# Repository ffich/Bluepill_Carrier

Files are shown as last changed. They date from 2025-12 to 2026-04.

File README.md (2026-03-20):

# BluePill Experimental Carrier

🧪 **BluePill Experimental Carrier** is a carrier board designed for development, testing, and rapid experimentation with the **STM32 Blue Pill (STM32F103)**.

The goal of this board is to provide a **feature-rich development platform** with integrated peripherals, industrial communication interfaces, and expansion sockets, while keeping the design clean, educational, and easy to extend.

---

## ✨ Key Features

### On-board Peripherals
- 14 × Status / debug LEDs  
- 3 × User buttons  
- 1 × Wake-up button  
- 1 × Analog potentiometer  
- **TMP102** I2C temperature sensor  
- **I²C OLED** display  
- **SPI EEPROM**  

### Communications
- **CAN bus TJA1051T3** transceiver
- **LIN Bus TJA1029T** transceiver (Configurable Master/Slave)
- **RS-485** interface with dedicated transceiver
- **USB / Serial** interface

### Security
- **Microchip ATECC608C** Cryptographic coprocessor

### Expansion Sockets
- External **DS3231 RTC Breakout** socket  
- **BME280** environmental sensor socket  



---

## 🎯 Design Philosophy

- Built for **experimentation, prototyping, and hardware/software testing**
- Well suited for:
  - Embedded development
  - Industrial and automotive communications (CAN, LIN, RS-485)
  - Sensor integration
  - Industrial and IoT applications
  - Cybersecurity

---

## 🧩 Target Audience

- Advanced makers  
- Electronics / embedded students  
- STM32 firmware developers  
- Educational labs and R&D teams  

---

## ⚠️ Disclaimer

This board is **experimental by design**.  
Layout, features, and routing may evolve as the project progresses and new tests are performed.

---

## 📜 License

Hardware and documentation are released under an open-source license.  
See the `LICENSE` file for details.

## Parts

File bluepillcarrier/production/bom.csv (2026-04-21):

Designator | Footprint | Quantity | Value | LCSC Part #
C1, C2, C3, C4, C5, C6 | 0402 | 6 | 100nF | C155422
CN1 | USB_C_Receptacle_HRO_TYPE-C-31-M-12 | 1 | USB | C165948
CN10 | PinSocket_1x07_P2.54mm_Vertical | 1 | IO | C22438157
CN11 | JST_SH_SM04B-SRSS-TB_1x04-1MP_P1.00mm_Horizontal | 1 | QWIIC | C160404
CN2 | PhoenixContact_MSTBA_2,5_2-G-5,08_1x02_P5.08mm_Horizontal | 1 | Can | C441204
CN4 | PinSocket_1x06_P2.54mm_Vertical | 1 | RTC | C2832269
CN5 | PhoenixContact_MSTBA_2,5_2-G-5,08_1x02_P5.08mm_Horizontal | 1 | RS485 | C441204
CN7 | PinSocket_1x04_P2.54mm_Vertical | 1 | BME | C2718488
CN9 | PinHeader_1x03_P2.54mm_Vertical | 1 | Lin | C49257
D1 | D_SMA | 1 | D_Schottky | C412514
D2 | D_SOD-123 | 1 | 1N4148W | C2099
JP1 | PinHeader_1x02_P2.54mm_Vertical | 1 | CAN Term | C5360898
JP2 | PinHeader_1x02_P2.54mm_Vertical | 1 | RS485 Term | C5360898
JP3 | PinHeader_1x02_P2.54mm_Vertical | 1 | USB pwr | C5360898
JP4 | PinHeader_1x03_P2.54mm_Vertical | 1 | Lin_Vbat | C49257
JP5 | PinHeader_1x02_P2.54mm_Vertical | 1 | Lin master | C5360898
LD1, LD10, LD11, LD12, LD13, LD14, LD15, LD16, LD2, LD3, LD4, LD5, LD6, LD9 | 0603 | 14 | Led Blue | C2288
LD7, LD8 | 0603 | 2 | Led Red | C2286
MODULE1A | YAAJ_BluePill_SWD_1 | 1 | YAAJ_BluePill_Part_Like_SWD_Breakout | C2905423
MODULE1B | YAAJ_BluePill_SWD_1 | 1 | YAAJ_BluePill_Part_Like_SWD_Breakout | C2905423
OLED1 | MODULE_DM-OLED096-636 | 1 | OLED | C5248080
R1, R12, R13, R19, R22, R24, R26, R3, R7 | 0402 | 9 | 10k | C174175
R10, R11, R17, R18, R2, R20, R21, R23, R27, R28, R29, R30, R31, R32, R4, R6, R9 | 0402 | 17 | 1k | C140196
R14, R15 | 0603 | 2 | 2.2k
R16, R25 | 0603 | 2 | 120 | C177328
R5, R8 | 0402 | 2 | 5.1k | C25905
RV1 | Potentiometer_Bourns_3386P_Vertical | 1 | Tr | C116303
SW1, SW2, SW3, SW4 | SW_SPST_PTS810 | 4 | Usr1 | C221895
U1 | JEITA_SOIC-8_3.9x4.9mm_P1.27mm | 1 | CH340N | C2977777
U2 | SOIC-8_3.9x4.9mm_P1.27mm | 1 | M95512-WMN6TP | C7567
U3 | SOIC-8_3.9x4.9mm_P1.27mm | 1 | TJA1051T-3 | C38695
U4 | SOT-563 | 1 | TMP102xxDRL | C99269
U5 | SOIC-8_3.9x4.9mm_P1.27mm | 1 | TJA1029T | C194435
U6 | SOIC-8_3.9x4.9mm_P1.27mm | 1 | MAX3485EESA+T | C9943
U7 | SOIC-8_3.9x4.9mm_P1.27mm | 1 | ATECC608A-SSHDA | C28975195

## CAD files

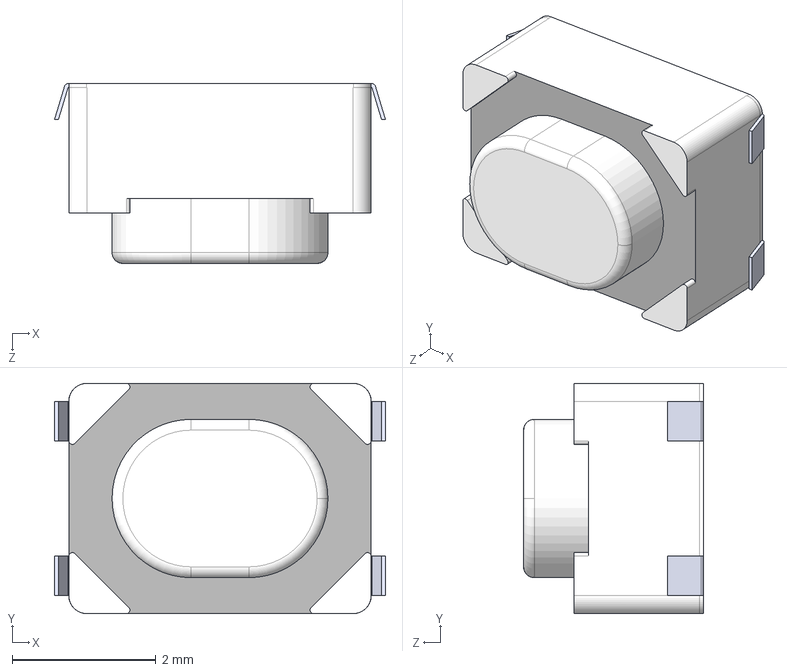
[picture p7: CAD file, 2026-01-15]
bluepillcarrier/3d/PTS810 Series SJS 250.STEP
4.60 x 3.20 x 2.50 mm

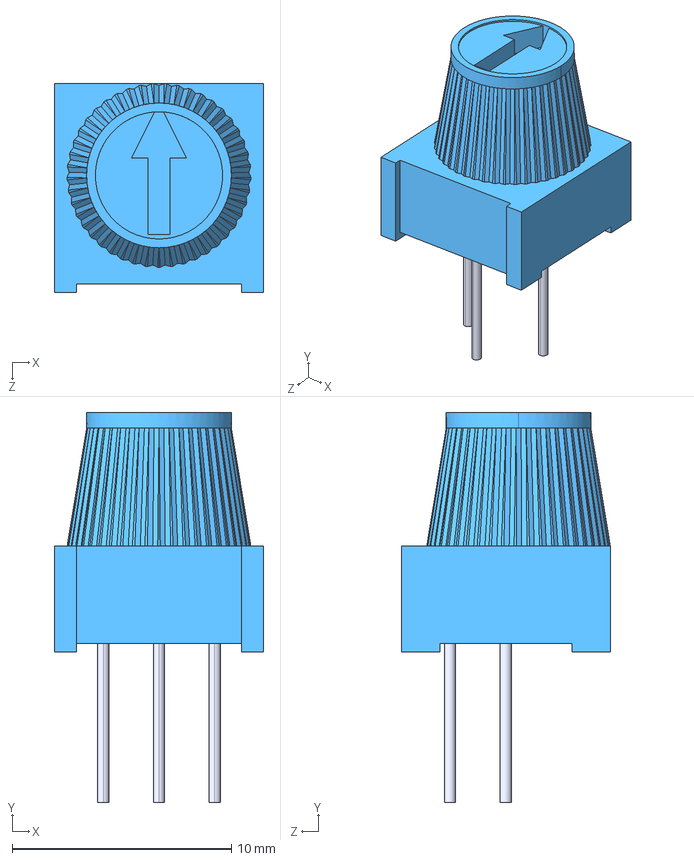
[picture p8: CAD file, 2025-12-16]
bluepillcarrier/3d/3386P-1-104TLF.STEP
9.53 x 17.8 x 9.53 mm

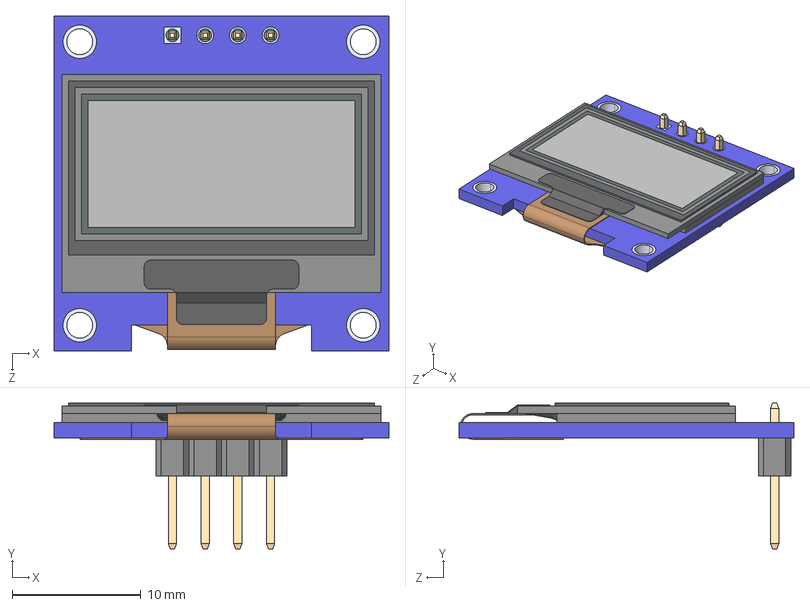
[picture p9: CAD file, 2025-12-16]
bluepillcarrier/3d/DM-OLED096-636--3DModel-STEP-56544.STEP
26.0 x 11.3 x 26.0 mm
DM-OLED096-636_Module
DM-OLED096-636_Panel

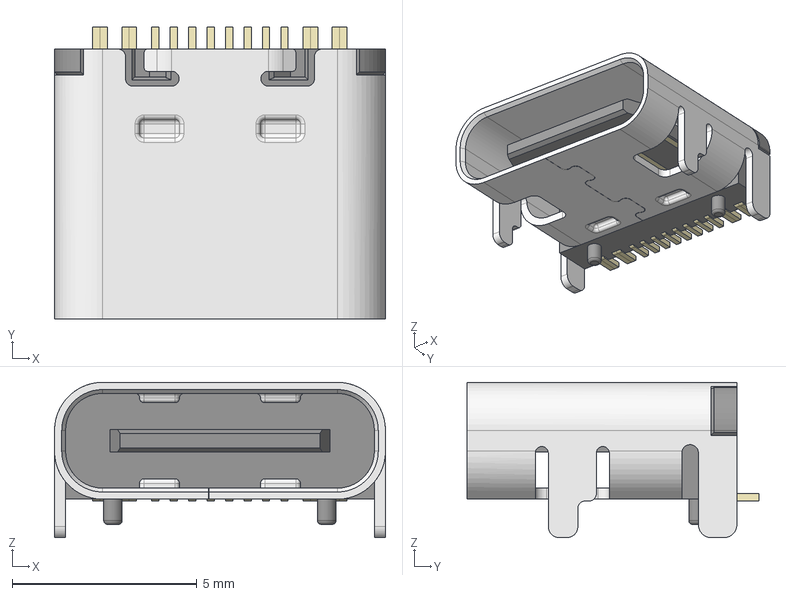
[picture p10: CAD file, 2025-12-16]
bluepillcarrier/3d/HRO_TYPE-C-31-M-12.step
8.95 x 7.90 x 4.20 mm

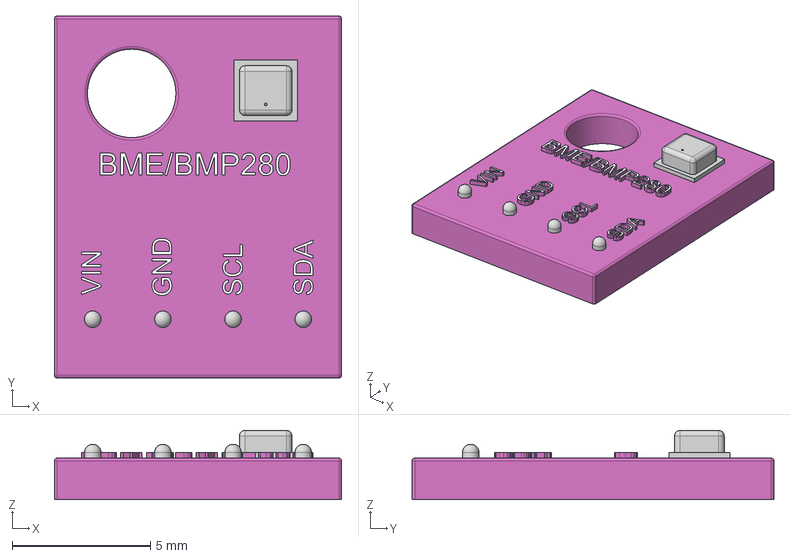
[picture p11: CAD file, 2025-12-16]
bluepillcarrier/3d/BME280 v6.step
10.4 x 13.1 x 2.50 mm

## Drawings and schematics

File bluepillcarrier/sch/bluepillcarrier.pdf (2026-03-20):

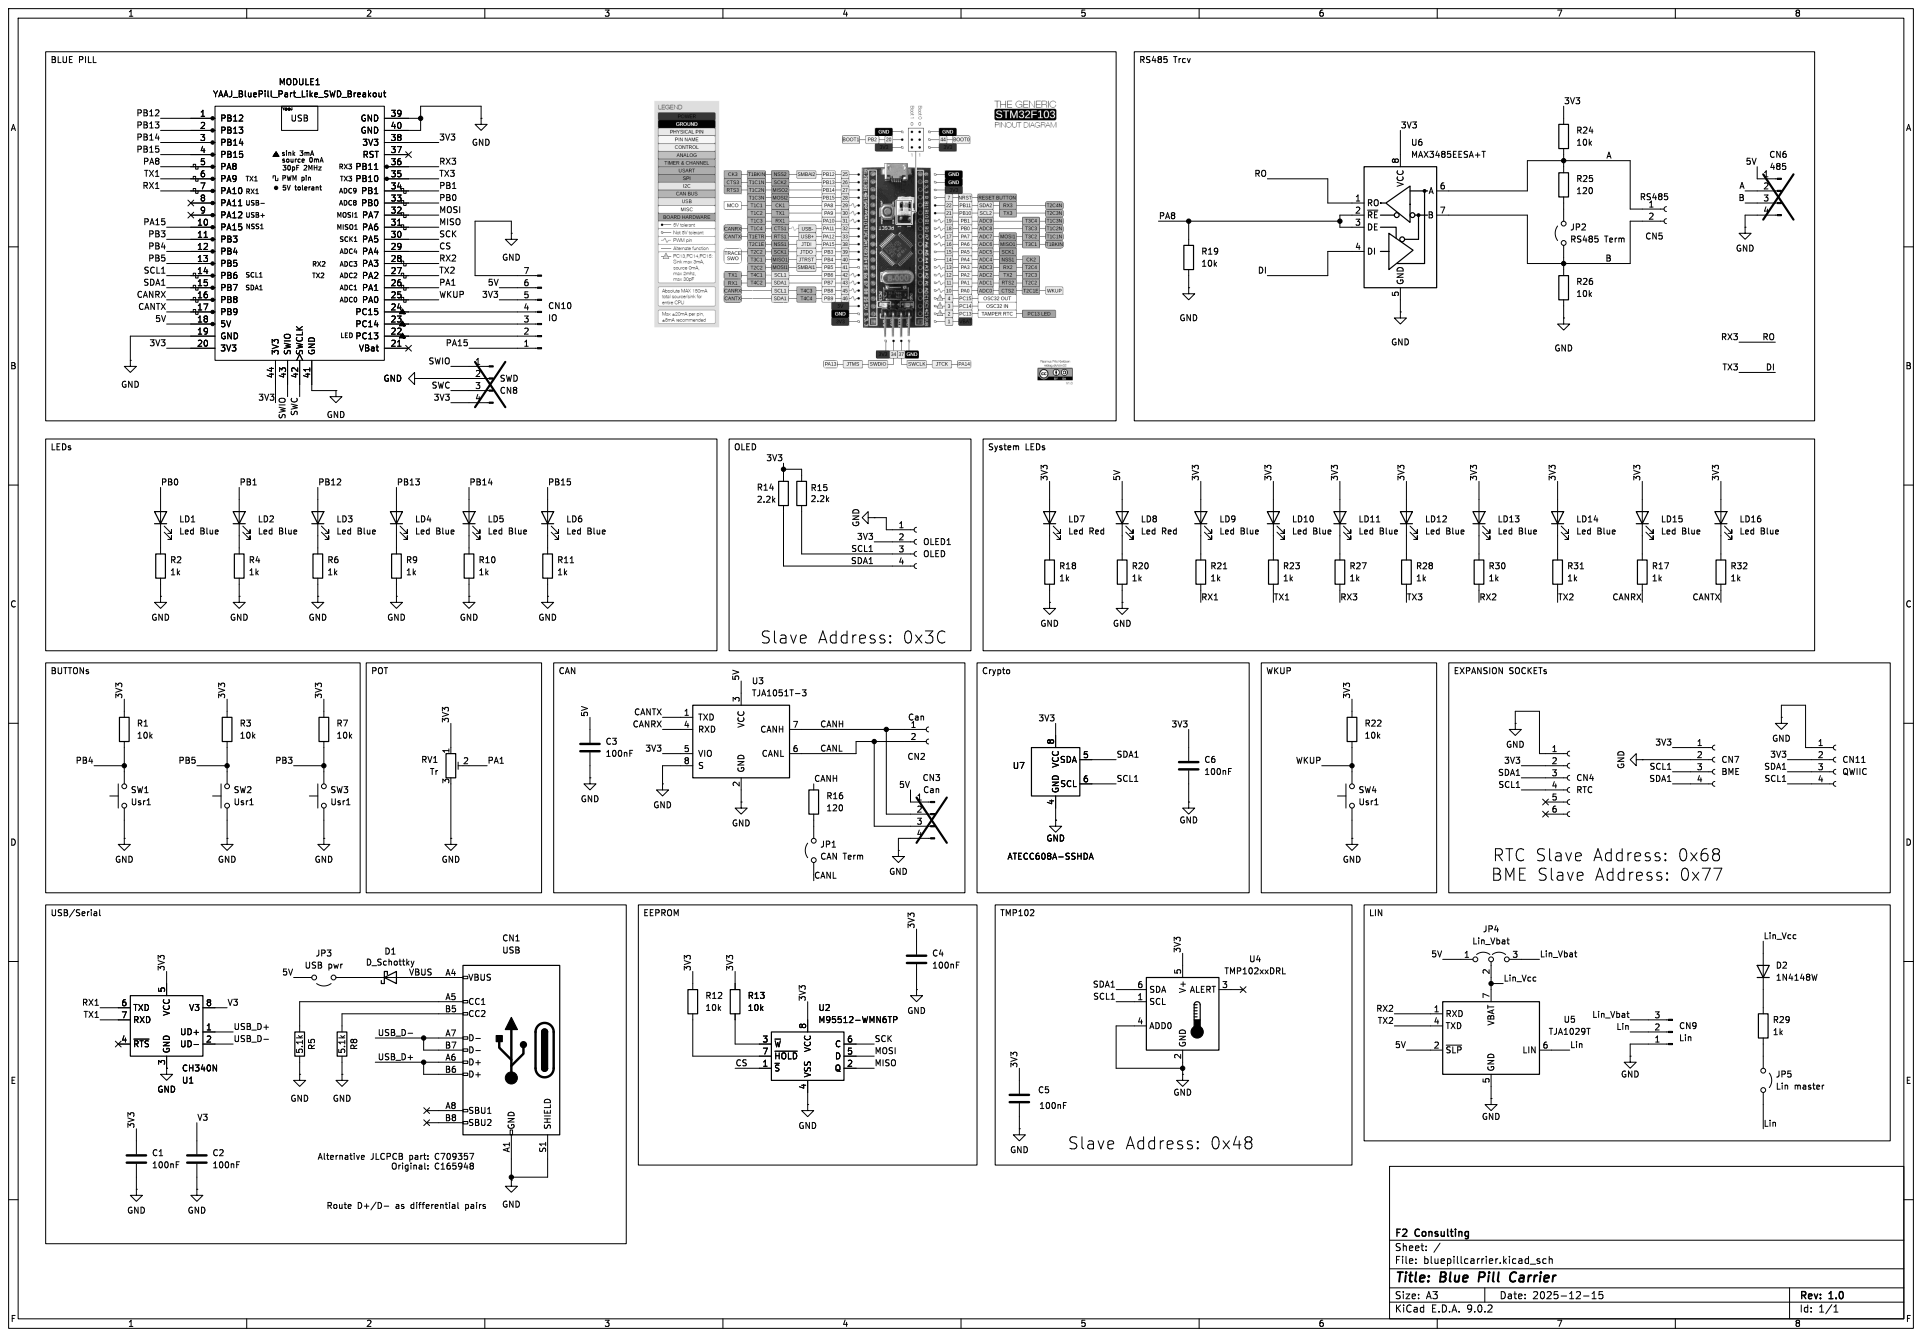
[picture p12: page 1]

Led Blue CANTX CANRX

3 TXD 6 RXD 7 ~{RTS} 4 GND

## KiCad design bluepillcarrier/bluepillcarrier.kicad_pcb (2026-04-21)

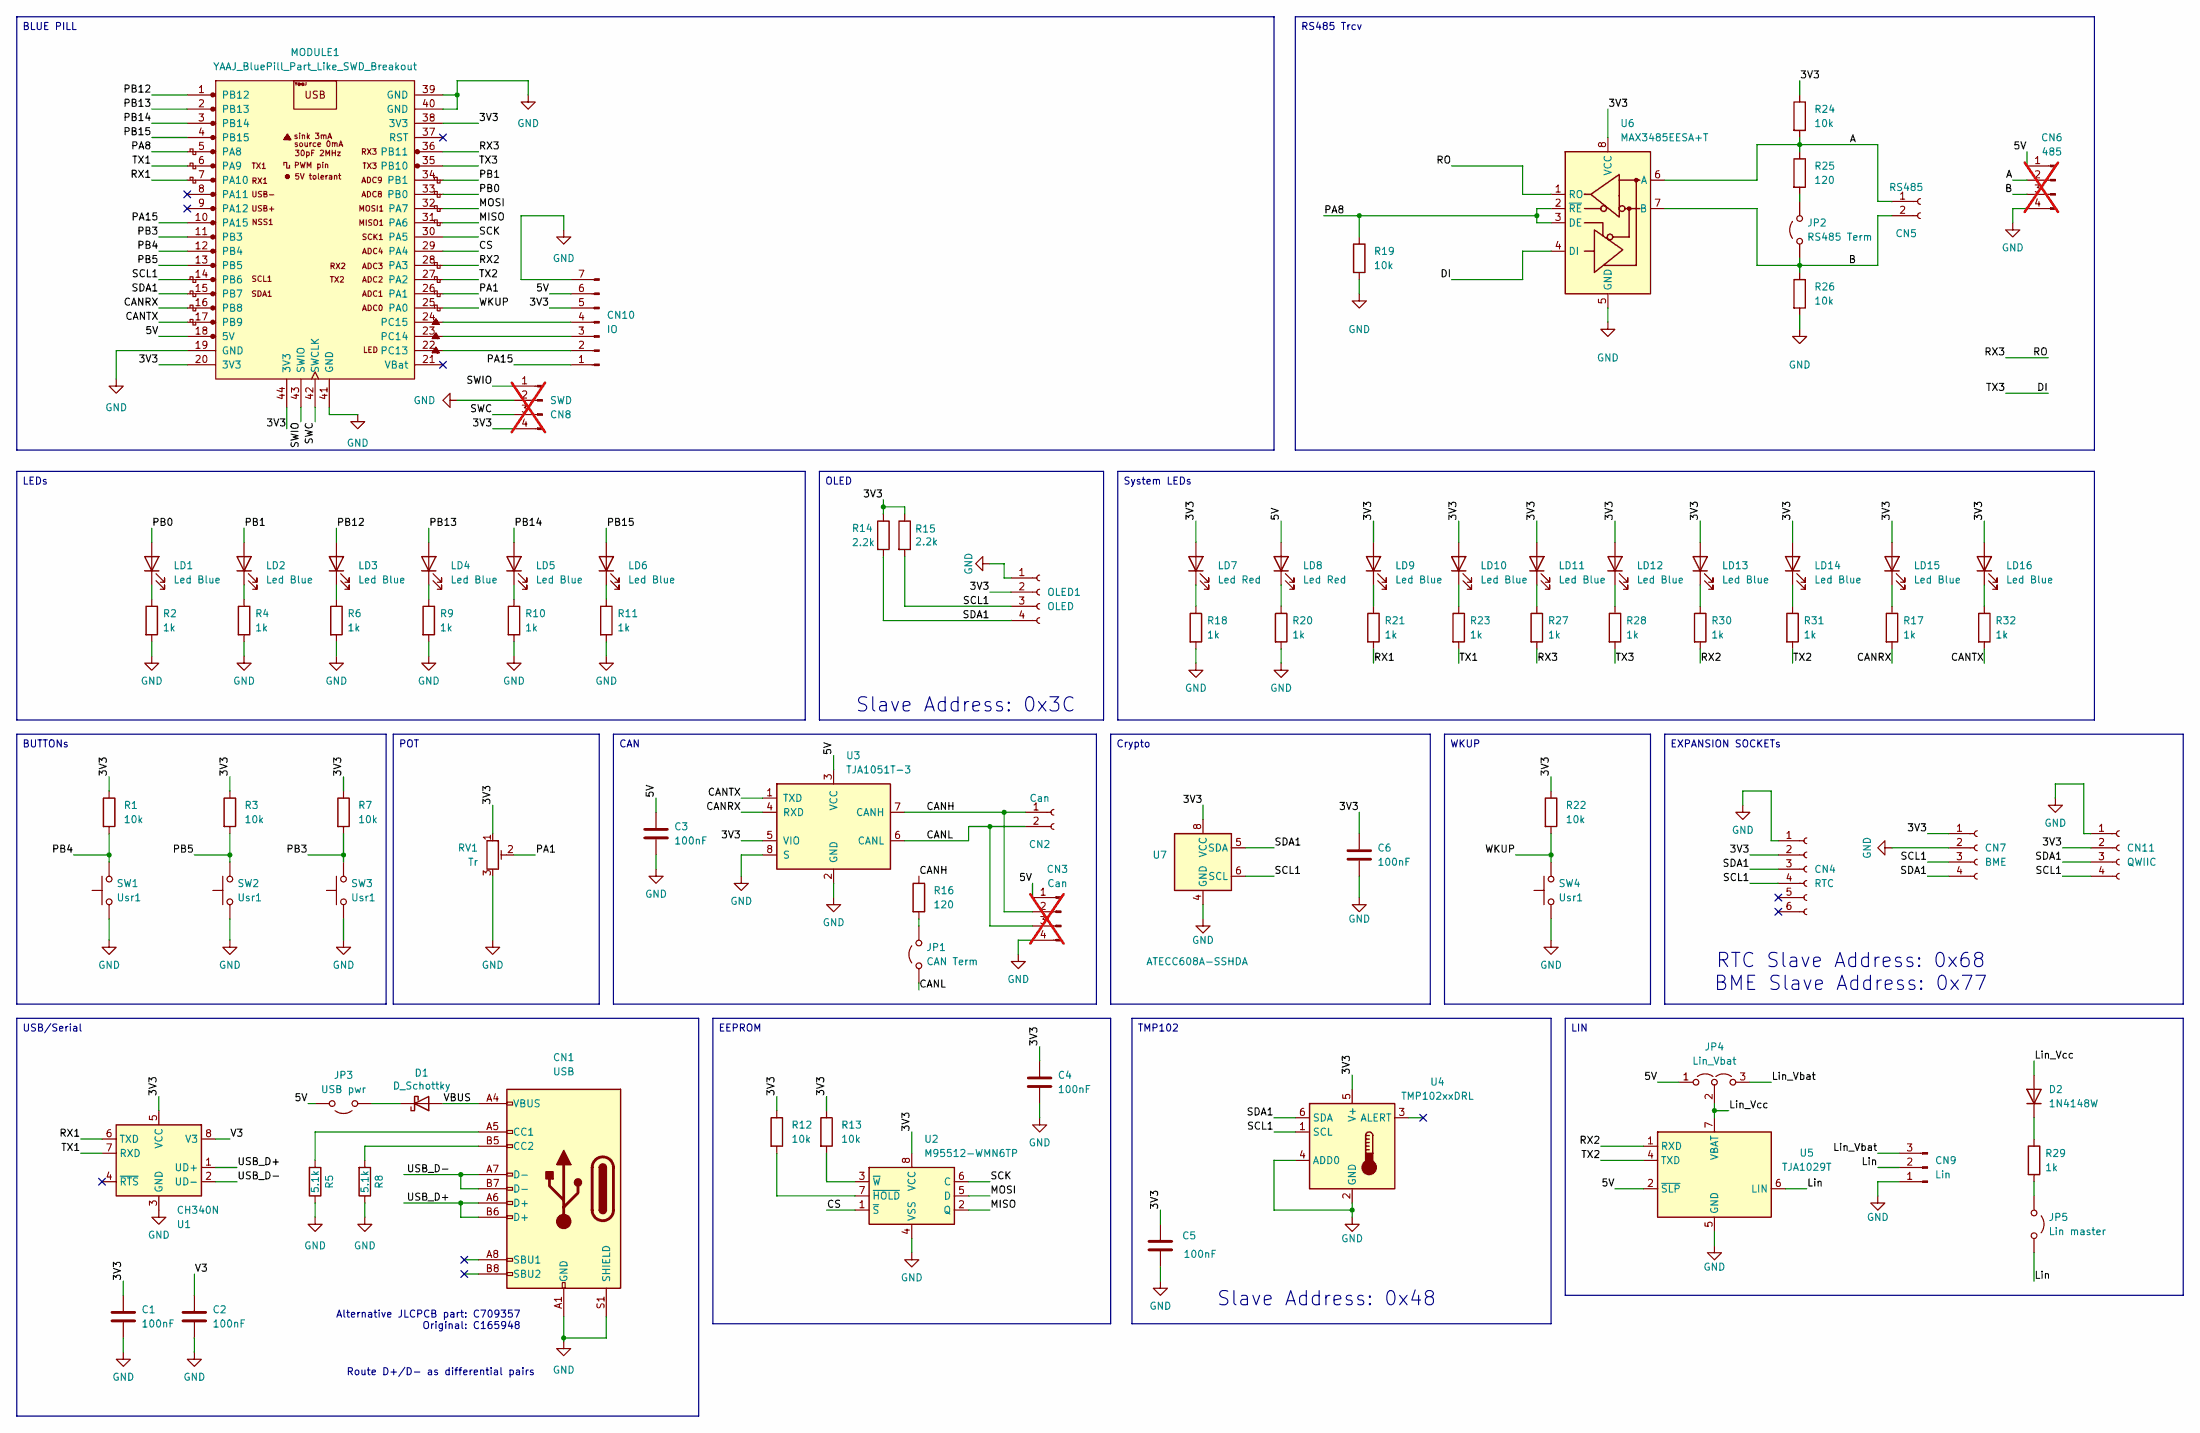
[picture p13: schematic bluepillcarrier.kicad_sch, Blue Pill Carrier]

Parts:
C1, C2, C3, C4, C5, C6: 100nF; C_0402_1005Metric; LCSC C155422
CN1: USB; USB_C_Receptacle_HRO_TYPE-C-31-M-12; LCSC C165948
CN2: Can; PhoenixContact_MSTBA_2,5_2-G-5,08_1x02_P5.08mm_Horizontal; LCSC C441204
CN3: Can; PinHeader_1x04_P2.54mm_Vertical; LCSC C2905435; not fitted
CN4: RTC; PinSocket_1x06_P2.54mm_Vertical; LCSC C2832269
CN5: RS485; PhoenixContact_MSTBA_2,5_2-G-5,08_1x02_P5.08mm_Horizontal; LCSC C441204
CN6: 485; PinHeader_1x04_P2.54mm_Vertical; LCSC C2905435; not fitted
CN7: BME; PinSocket_1x04_P2.54mm_Vertical; LCSC C2718488
CN8: SWD; PinHeader_1x04_P2.54mm_Vertical; not fitted
CN9: Lin; PinHeader_1x03_P2.54mm_Vertical; LCSC C49257
CN10: IO; PinSocket_1x07_P2.54mm_Vertical; LCSC C22438157
CN11: QWIIC; JST_SH_SM04B-SRSS-TB_1x04-1MP_P1.00mm_Horizontal; LCSC C160404
D1: D_Schottky; D_SMA; LCSC C412514
D2: 1N4148W; D_SOD-123; LCSC C2099
JP1: CAN Term; PinHeader_1x02_P2.54mm_Vertical; LCSC C5360898
JP2: RS485 Term; PinHeader_1x02_P2.54mm_Vertical; LCSC C5360898
JP3: USB pwr; PinHeader_1x02_P2.54mm_Vertical; LCSC C5360898
JP4: Lin_Vbat; PinHeader_1x03_P2.54mm_Vertical; LCSC C49257
JP5: Lin master; PinHeader_1x02_P2.54mm_Vertical; LCSC C5360898
LD1, LD2, LD3, LD4, LD5, LD6, LD9, LD10, LD11, LD12, LD13, LD14, LD15, LD16: Led Blue; LED_0603_1608Metric; LCSC C2288
LD7, LD8: Led Red; LED_0603_1608Metric; LCSC C2286
MODULE1: YAAJ_BluePill_Part_Like_SWD_Breakout; YAAJ_BluePill_SWD_1; LCSC C2905423
OLED1: OLED; MODULE_DM-OLED096-636; LCSC C5248080
R1, R3, R7, R12, R13, R19, R22, R24, R26: 10k; R_0402_1005Metric; LCSC C174175
R2, R4, R6, R9, R10, R11, R17, R18, R20, R21, R23, R27, R28, R29, R30, R31, R32: 1k; R_0402_1005Metric; LCSC C140196
R5, R8: 5.1k; R_0402_1005Metric; LCSC C25905
R14, R15: 2.2k; R_0603_1608Metric
R16, R25: 120; R_0603_1608Metric; LCSC C177328
RV1: Tr; Potentiometer_Bourns_3386P_Vertical; LCSC C116303
SW1, SW2, SW3, SW4: Usr1; SW_SPST_PTS810; LCSC C221895
U1: CH340N; JEITA_SOIC-8_3.9x4.9mm_P1.27mm; LCSC C2977777
U2: M95512-WMN6TP; SOIC-8_3.9x4.9mm_P1.27mm; LCSC C7567
U3: TJA1051T-3; SOIC-8_3.9x4.9mm_P1.27mm; LCSC C38695
U4: TMP102xxDRL; SOT-563; LCSC C99269
U5: TJA1029T; SOIC-8_3.9x4.9mm_P1.27mm; LCSC C194435
U6: MAX3485EESA+T; SOIC-8_3.9x4.9mm_P1.27mm; LCSC C9943
U7: ATECC608A-SSHDA; SOIC-8_3.9x4.9mm_P1.27mm; LCSC C28975195

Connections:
/3V3: C1.1, C4.1, C5.1, C6.1, CN4.2, CN7.1, CN8.4, CN10.5, CN11.2, LD7.2 (A), LD9.2 (A), LD10.2 (A), LD11.2 (A), LD12.2 (A), LD13.2 (A), LD14.2 (A), LD15.2 (A), LD16.2 (A), MODULE1.20 (3V3), MODULE1.38 (3V3), MODULE1.44 (3V3), OLED1.2, R1.1, R3.1, R7.1, R12.1, R13.1, R14.1, R15.1, R22.1, R24.1, RV1.1, U1.5 (VCC), U2.8 (VCC), U3.5 (VIO), U4.5 (V+), U6.8 (VCC), U7.8 (VCC)
/5V: C3.1, CN3.1, CN6.1, CN10.6, JP3.2 (B), JP4.1 (A), LD8.2 (A), MODULE1.18 (5V), U3.3 (VCC), U5.2 (~SLP)
/A: CN5.1, CN6.2, R24.2, R25.1, U6.6 (A)
/B: CN5.2, CN6.3, JP2.1 (A), R26.1, U6.7 (B)
/CANH: CN2.1, CN3.2, R16.1, U3.7 (CANH)
/CANL: CN2.2, CN3.3, JP1.1 (A), U3.6 (CANL)
/CANRX: MODULE1.16 (PB8), R17.2, U3.4 (RXD)
/CANTX: MODULE1.17 (PB9), R32.2, U3.1 (TXD)
/CS: MODULE1.29 (PA4), U2.1 (~S)
/DI: MODULE1.35 (PB10), R28.2, U6.4 (DI)
/Lin: CN9.2, JP5.2 (B), U5.6 (LIN)
/Lin_Vbat: CN9.3, JP4.3 (B)
/Lin_Vcc: D2.2 (A), JP4.2 (C), U5.7 (VBAT)
/MISO: MODULE1.31 (PA6), U2.2 (Q)
/MOSI: MODULE1.32 (PA7), U2.5 (D)
/PA1: MODULE1.26 (PA1), RV1.2
/PA8: MODULE1.5 (PA8), R19.1, U6.2 (~RE), U6.3 (DE)
/PA15: CN10.1, MODULE1.10 (PA15)
/PB0: LD1.2 (A), MODULE1.33 (PB0)
/PB1: LD2.2 (A), MODULE1.34 (PB1)
/PB3: MODULE1.11 (PB3), R7.2, SW3.2
/PB4: MODULE1.12 (PB4), R1.2, SW1.2
/PB5: MODULE1.13 (PB5), R3.2, SW2.2
/PB12: LD3.2 (A), MODULE1.1 (PB12)
/PB13: LD4.2 (A), MODULE1.2 (PB13)
/PB14: LD5.2 (A), MODULE1.3 (PB14)
/PB15: LD6.2 (A), MODULE1.4 (PB15)
/RO: MODULE1.36 (PB11), R27.2, U6.1 (RO)
/RX1: MODULE1.7 (PA10), R21.2, U1.6 (TXD)
/RX2: MODULE1.28 (PA3), R30.2, U5.1 (RXD)
/SCK: MODULE1.30 (PA5), U2.6 (C)
/SCL1: CN4.4, CN7.3, CN11.4, MODULE1.14 (PB6), OLED1.3, R15.2, U4.1 (SCL), U7.6 (SCL)
/SDA1: CN4.3, CN7.4, CN11.3, MODULE1.15 (PB7), OLED1.4, R14.2, U4.6 (SDA), U7.5 (SDA)
/SWC: CN8.3, MODULE1.42 (SWCLK)
/SWIO: CN8.1, MODULE1.43 (SWIO)
/TX1: MODULE1.6 (PA9), R23.2, U1.7 (RXD)
/TX2: MODULE1.27 (PA2), R31.2, U5.4 (TXD)
/USB_D+: CN1.A6 (D+), CN1.B6 (D+), U1.1 (UD+)
/USB_D-: CN1.A7 (D-), CN1.B7 (D-), U1.2 (UD-)
/V3: C2.1, U1.8 (V3)
/VBUS: CN1.A4 (VBUS), CN1.A9 (VBUS), CN1.B4 (VBUS), CN1.B9 (VBUS), D1.2 (A)
/WKUP: MODULE1.25 (PA0), R22.2, SW4.2
GND: C1.2, C2.2, C3.2, C4.2, C5.2, C6.2, CN1.A1 (GND), CN1.A12 (GND), CN1.B1 (GND), CN1.B12 (GND), CN1.S1 (SHIELD), CN3.4, CN4.1, CN6.4, CN7.2, CN8.2, CN9.1, CN10.7, CN11.1, MODULE1.19 (GND), MODULE1.39 (GND), MODULE1.40 (GND), MODULE1.41 (GND), OLED1.1, R2.2, R4.2, R5.1, R6.2, R8.1, R9.2, R10.2, R11.2, R18.2, R19.2, R20.2, R26.2, RV1.3, SW1.1, SW2.1, SW3.1, SW4.1, U1.3 (GND), U2.4 (VSS), U3.2 (GND), U3.8 (S), U4.2 (GND), U4.4 (ADD0), U5.5 (GND), U6.5 (GND), U7.4 (GND)
unnamed: CN1.A5 (CC1), R5.2
unnamed: CN1.B5 (CC2), R8.2
unnamed: CN10.2, MODULE1.22 (PC13)
unnamed: CN10.3, MODULE1.23 (PC14)
unnamed: CN10.4, MODULE1.24 (PC15)
unnamed: D1.1 (K), JP3.1 (A)
unnamed: D2.1 (K), R29.1
unnamed: JP1.2 (B), R16.2
unnamed: JP2.2 (B), R25.2
unnamed: JP5.1 (A), R29.2
unnamed: LD1.1 (K), R2.1
unnamed: LD2.1 (K), R4.1
unnamed: LD3.1 (K), R6.1
unnamed: LD4.1 (K), R9.1
unnamed: LD5.1 (K), R10.1
unnamed: LD6.1 (K), R11.1
unnamed: LD7.1 (K), R18.1
unnamed: LD8.1 (K), R20.1
unnamed: LD9.1 (K), R21.1
unnamed: LD10.1 (K), R23.1
unnamed: LD11.1 (K), R27.1
unnamed: LD12.1 (K), R28.1
unnamed: LD13.1 (K), R30.1
unnamed: LD14.1 (K), R31.1
unnamed: LD15.1 (K), R17.1
unnamed: LD16.1 (K), R32.1
unnamed: R12.2, U2.7 (~HOLD)
unnamed: R13.2, U2.3 (~W)

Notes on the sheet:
Slave Address: 0x48
Route D+/D- as differential pairs
RTC Slave Address: 0x68 BME Slave Address: 0x77
Alternative JLCPCB part: C709357 Original: C165948
Slave Address: 0x3C
WKUP
EXPANSION SOCKETs
USB/Serial
RS485 Trcv
LIN
BUTTONs
BLUE PILL
System LEDs
EEPROM
CAN
LEDs
Crypto
POT
TMP102
OLED

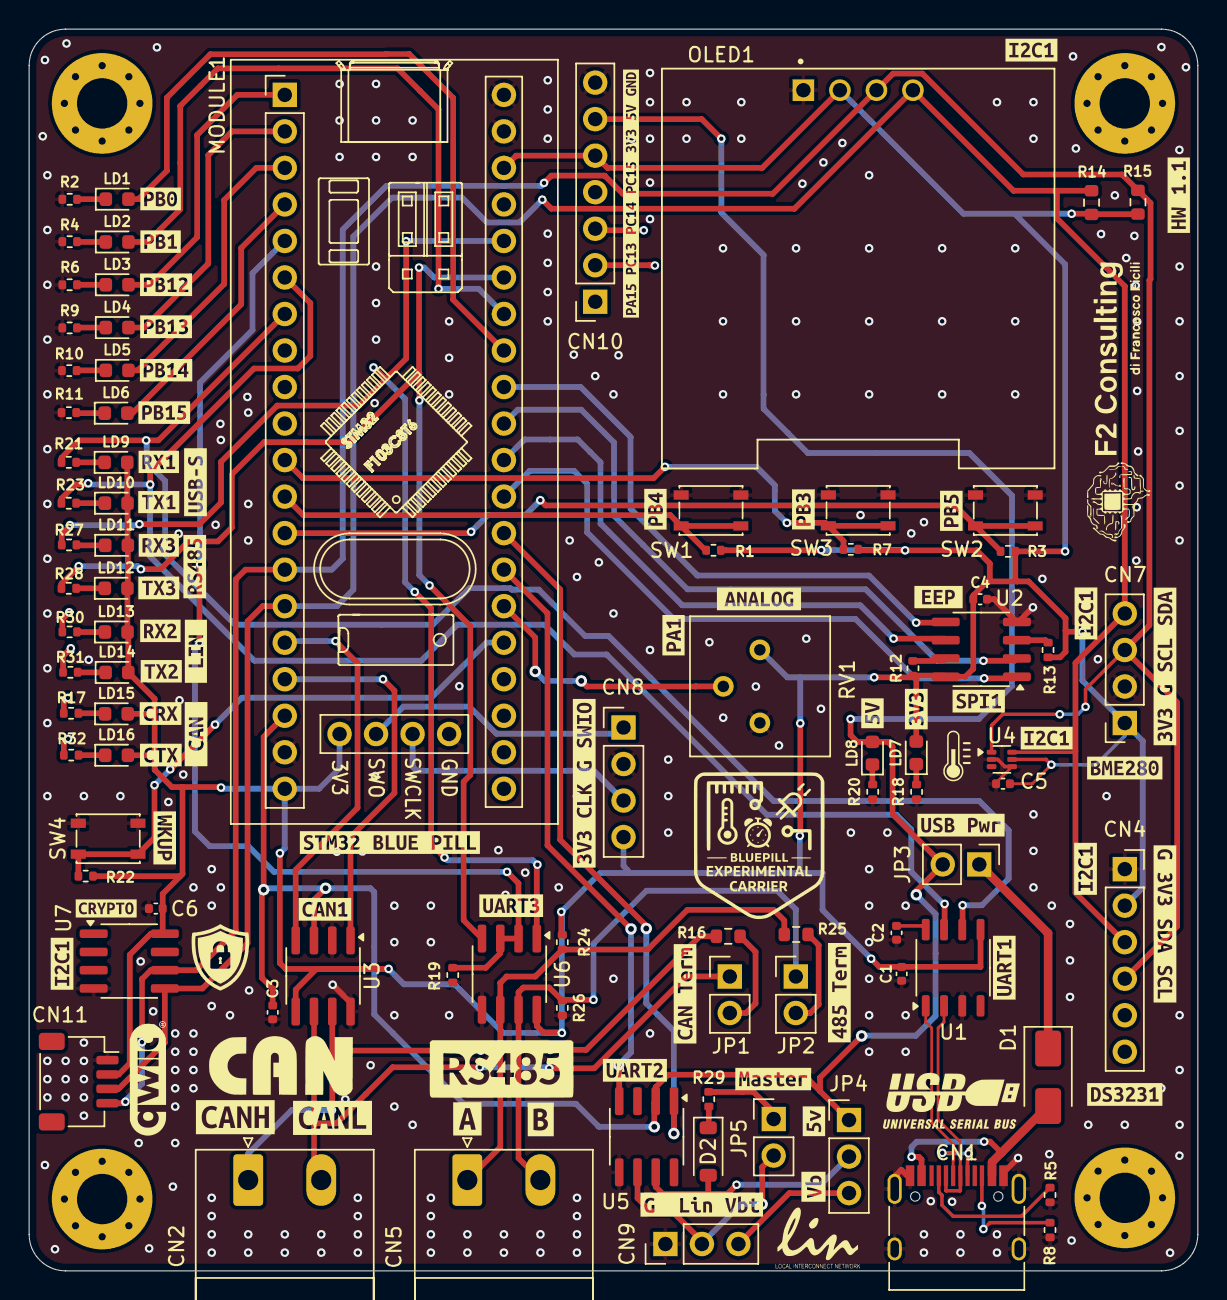
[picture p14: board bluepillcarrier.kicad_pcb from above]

Board: 4 copper layers, 81.3 x 86.4 mm, 141 parts (0 on the bottom side), 71 nets.

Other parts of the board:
kibuzzard-695AB37B: G***; kibuzzard-695AB37B
kibuzzard-695AB373: G***; kibuzzard-695AB373
kibuzzard-696A2AD8: G***; kibuzzard-696A2AD8
kibuzzard-696A4D9E: G***; kibuzzard-696A4D9E
kibuzzard-696A4D49: G***; kibuzzard-696A4D49
kibuzzard-696A4D50: G***; kibuzzard-696A4D50
kibuzzard-696A23BE: G***; kibuzzard-696A23BE
kibuzzard-696A233A: G***; kibuzzard-696A233A
kibuzzard-696A237E: G***; kibuzzard-696A237E
kibuzzard-696A2374: G***; kibuzzard-696A2374
kibuzzard-69594BD1: G***; kibuzzard-69594BD1
kibuzzard-69594BE1: G***; kibuzzard-69594BE1
kibuzzard-69594BEF: G***; kibuzzard-69594BEF
kibuzzard-69594BFB: G***; kibuzzard-69594BFB
kibuzzard-69594C3C: G***; kibuzzard-69594C3C
kibuzzard-69594C6D: G***; kibuzzard-69594C6D
kibuzzard-69594C8A: G***; kibuzzard-69594C8A
kibuzzard-69594C8F: G***; kibuzzard-69594C8F
kibuzzard-69594C11: G***; kibuzzard-69594C11
kibuzzard-69594C18: G***; kibuzzard-69594C18
kibuzzard-69594C37: G***; kibuzzard-69594C37
kibuzzard-69594C59: G***; kibuzzard-69594C59
kibuzzard-69594C68: G***; kibuzzard-69594C68
kibuzzard-69594C94: G***; kibuzzard-69594C94
kibuzzard-69594CA2: G***; kibuzzard-69594CA2
kibuzzard-69594D1B: G***; kibuzzard-69594D1B
kibuzzard-69594D2D: G***; kibuzzard-69594D2D
kibuzzard-69594D3A: G***; kibuzzard-69594D3A
kibuzzard-69594D5C: G***; kibuzzard-69594D5C
kibuzzard-69594D06: G***; kibuzzard-69594D06
kibuzzard-69594D9E: G***; kibuzzard-69594D9E
kibuzzard-69594D45: G***; kibuzzard-69594D45
kibuzzard-69594D50: G***; kibuzzard-69594D50
kibuzzard-69594D57: G***; kibuzzard-69594D57
kibuzzard-69594D63: G***; kibuzzard-69594D63
kibuzzard-69594DB5: G***; kibuzzard-69594DB5
kibuzzard-69594DEB, kibuzzard-69594DEB#2, kibuzzard-69594DEB#3, kibuzzard-69594DEB#4, kibuzzard-69594DEB#5: G***; kibuzzard-69594DEB
kibuzzard-69594E2D: G***; kibuzzard-69594E2D
kibuzzard-69594E7B: G***; kibuzzard-69594E7B
kibuzzard-69636EB7: G***; kibuzzard-69636EB7
kibuzzard-69636ED7: G***; kibuzzard-69636ED7
kibuzzard-69636EE0: G***; kibuzzard-69636EE0
kibuzzard-69636EED: G***; kibuzzard-69636EED
kibuzzard-69908B33: G***; kibuzzard-69908B33
kibuzzard-69908F2A: G***; kibuzzard-69908F2A
kibuzzard-69908F16: G***; kibuzzard-69908F16
kibuzzard-69908F24: G***; kibuzzard-69908F24
kibuzzard-69909E2E: G***; kibuzzard-69909E2E
kibuzzard-694153A1: G***; kibuzzard-694153A1
kibuzzard-694153B4: G***; kibuzzard-694153B4
kibuzzard-69415277: G***; kibuzzard-69415277
kibuzzard-69415288: G***; kibuzzard-69415288
kibuzzard-69909054: G***; kibuzzard-69909054

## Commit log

2025-12-16 Added carrier project
    [3386P-1-104TLF.STEP, BME280 v6.step, DM-OLED096-636--3DModel-STEP-56544.STEP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]
2025-12-17 Some updates and fixes
    [bluepillcarrier.kicad_pcb, bluepillcarrier.kicad_sch, bom.csv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]
2025-12-17 added bom
2026-01-03 Fixes: - Corrected OLED footprint - Green led resistor set to 1k - Updated all the labels to 1mm for better visibility - Moved trimmer a bit below to save a bit of space for buttons
    [bluepillcarrier.kicad_pcb, bluepillcarrier.kicad_sch]
2026-01-08 Some additional fixes
    [bluepillcarrier.kicad_pcb, bluepillcarrier.kicad_sch]
2026-01-11 some updates
    [bluepillcarrier.kicad_pcb, bluepillcarrier.kicad_sch, bom.csv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]
2026-01-15 Final design without LIN
    [bluepillcarrier.kicad_pcb]
2026-01-15 - changed temperature sensor
    [bluepillcarrier.kicad_pcb, bluepillcarrier.kicad_sch]
2026-01-18 some minor modifications
    [bluepillcarrier.kicad_pcb, bluepillcarrier.kicad_sch, positions.csv]
2026-03-20 Updated schematic and ibom
2026-04-21 Some changes/fixes: -Fixed error on interface - Added TX/RX LEDs for CAN - Replaces Buzzer with ATECC608C crypto chip - Added QWIIC
    [bluepillcarrier.kicad_pcb, bom.csv, positions.csv]
